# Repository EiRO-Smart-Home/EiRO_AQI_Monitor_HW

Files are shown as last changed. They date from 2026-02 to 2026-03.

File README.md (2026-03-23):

# AQI monitor

This project is a developement board based on a MGM260PD32VNA2 Module from SiliconLabs, SEN5x series sensors and with support for ePaper and other SPI based displays.
This board has been realized for the lack of available options that would satisfy our need in therms of a good air quality sensor. As for most commercial solutions are expensive, or they lack some features, such as Matter connectivity or some types of enviromental sensing. Most of the time they detect only PM2.5 and not PM10 and some do not include VOCs. 
Our targets of sensing values are the followings.
- Temperature
- Humidity
- PM 1.0, PM 2.5, PM 4, PM10
- VOC (index)
- CO2 
- NOx
- Formaldehyde 
- Overall AQI index (calculated)
  
Most of the sensing can be done using SEN55 and two addittional sensors for Formaldehyde and CO2. A SEN69C can also be used, but VCC on the connector is 5V and newer SEN6x are 3.3V powered, so the board has to be modified.

An advantage of using Matter as the default connectivity standard, is the ease of integrating it in any smart home (with also a Thread Border Router). There is no need for vendor specific applications, as all the data will be managed by Matter. This means there is no need for subscription and the device is completely local.

## Hardware Features

 - MGM260 SoM
   * BLE 5.4 Support 
   * Zigbee 3.0 and up
   * OpenThread
   * ARM Cortex M33 @ 80 MHz
   * 3.2MB Flash + 512kB RAM
   * Matrix Vector Processor for ML
 - SHT41 Temp. and Humidity Sensor
 - JTAG-SWD-9 connector
 - SPI expansion 4x2 1.27mm pitch
 - SPI connection for external display 
 - I2C expansion for external SEN5x series sensor node
 - USB-C for power and serial communication

## PICTURES

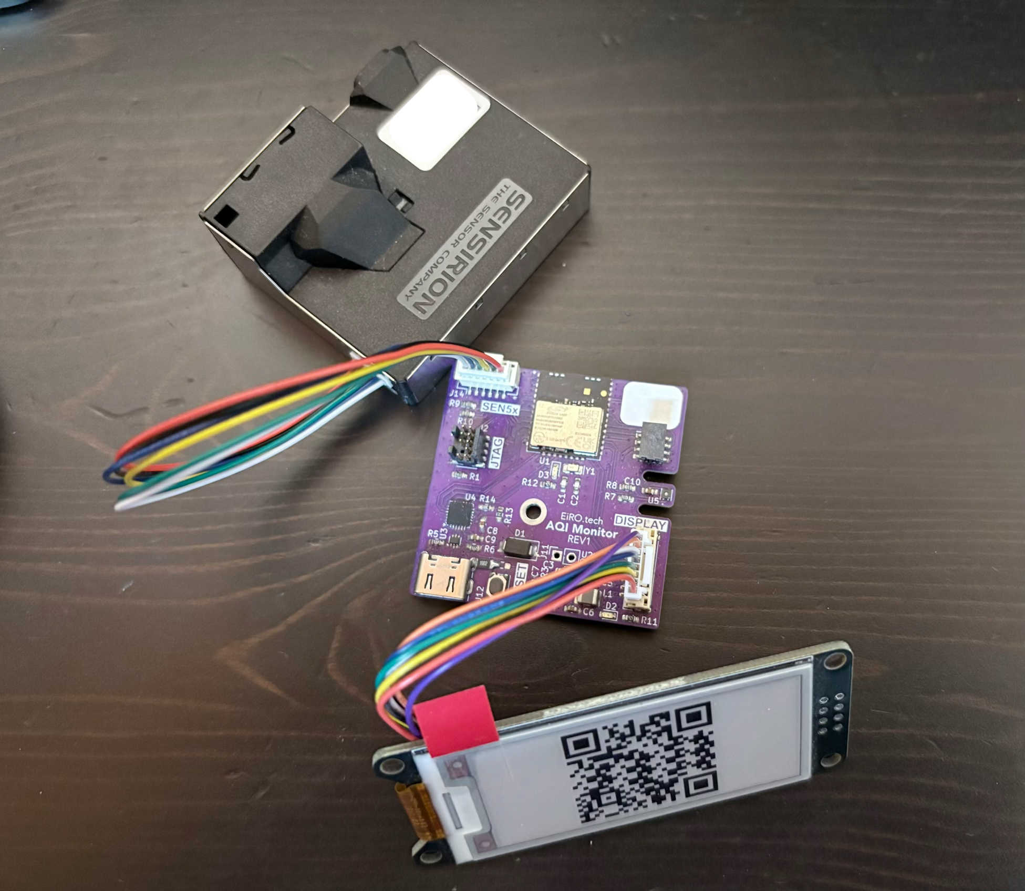
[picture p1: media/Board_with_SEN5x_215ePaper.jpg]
AQI Board with SEN5x


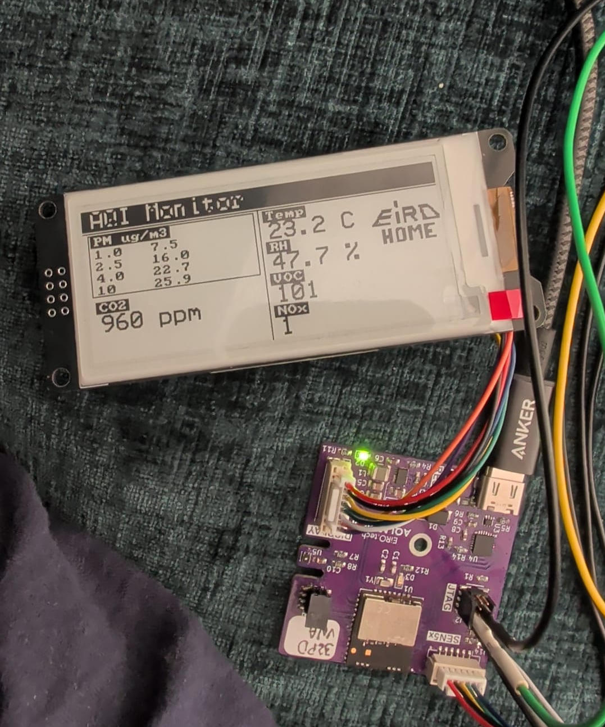
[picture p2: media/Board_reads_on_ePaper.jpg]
AQI Board ePaper_readings


## LICENSE

Copyright Francesco Salmaso - EiRO.tech 2025-2026
This source describes Open Hardware and is licensed under the CERN-
OHL-S v2.
You may redistribute and modify this source and make products using it
under the terms of the CERN-OHL-S v2
(https://ohwr.org/cern ohl s v2.txt ).
This source is distributed WITHOUT ANY EXPRESS OR IMPLIED
WARRANTY, INCLUDING OF MERCHANTABILITY, SATISFACTORY
QUALITY AND FITNESS FOR A PARTICULAR PURPOSE. Please see
the CERN-OHL-S v2 for applicable conditions.
Source location: https://github.com/EiRO-Smart-Home/EiRO_AQI_Monitor_HW
As per CERN-OHL-S v2 section 4, should You produce hardware based
on this source, You must where practicable maintain the Source Location
visible on the external case of the EiRO AQI Monitor or other products you make using
this source.

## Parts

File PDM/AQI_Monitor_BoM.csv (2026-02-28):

Id | Designator | Footprint | Quantity | Designation | Supplier and ref
1 | R14 | R_0603_1608Metric_Pad0.98x0.95mm_HandSolder | 1 | 47k5 |  | v | x
2 | C7 | C_0603_1608Metric_Pad1.08x0.95mm_HandSolder | 1 | 33pF |  | v | x
3 | R6,R5 | R_0603_1608Metric_Pad0.98x0.95mm_HandSolder | 2 | 5k1 |  | v | x
4 | C3 | C_0805_2012Metric_Pad1.18x1.45mm_HandSolder | 1 | 10uF |  | v | x
5 | J14 | JST_GH_BM06B-GHS-TBT_1x06-1MP_P1.25mm_Vertical | 1 | Conn_01x06 |  | ok
6 | R12,R11 | R_0603_1608Metric_Pad0.98x0.95mm_HandSolder | 2 | 470R |  | v | x
7 | C10,C8,C9,C6 | C_0603_1608Metric_Pad1.08x0.95mm_HandSolder | 4 | 100nF |  | v | x
8 | C1,C2 | C_0603_1608Metric_Pad1.08x0.95mm_HandSolder | 2 | 12pF |  | v | x
9 | D1 | D_SMA | 1 | D_Schottky |  | v | x
10 | U4 | QFN-24-1EP_4x4mm_P0.5mm_EP2.6x2.6mm | 1 | CP2102N-Axx-xQFN24 |  | v | x
11 | SW1 | SW_SPST_PTS810 | 1 | SW_Push |  | v | x
12 | R8,R7,R9,R10 | R_0603_1608Metric_Pad0.98x0.95mm_HandSolder | 4 | 100k |  | v | x
13 | C4,C5 | C_0805_2012Metric_Pad1.18x1.45mm_HandSolder | 2 | 22uF |  | v | x
14 | J12 | USB_C_Receptacle_JAE_DX07S016JA1R1500 | 1 | USB_C_Receptacle_USB2.0_16P |  | ok
15 | U1 | MODULE_xGM260P_SIL | 1 | MGM260PB22VNA5 |  | v | xxx
16 | J1 | PinHeader_2x04_P1.27mm_Vertical_SMD | 1 | SPI_EXP |  | v | x
17 | R1 | R_0603_1608Metric_Pad0.98x0.95mm_HandSolder | 1 | 100R |  | v | x
18 | D3,D2 | D_0603_1608Metric_Pad1.05x0.95mm_HandSolder | 2 | LED |  | v | xx
19 | R3 | R_0603_1608Metric_Pad0.98x0.95mm_HandSolder | 1 | 91k |  | v | x
20 | U2 | V-DFN3020-13_DIO | 1 | AP63357DV-7 |  | ok
21 | J11 | PinSocket_1x02_P2.54mm_Vertical | 1 | VIN |  | ok
22 | J13 | JST_GH_BM08B-GHS-TBT_1x08-1MP_P1.25mm_Vertical | 1 | Conn_01x08 |  | v | x
23 | L1 | L_1210_3225Metric_Pad1.42x2.65mm_HandSolder | 1 | 4.7uH |  | v | x
24 | Y1 | Crystal_SMD_MicroCrystal_CC8V-T1A-2Pin_2.0x1.2mm_HandSoldering | 1 | 32.768kHz |  | v | x
25 | J2 | PinHeader_2x05_P1.27mm_Vertical_SMD | 1 | Conn_ARM_JTAG_SWD_10 |  | v | x
26 | R4 | R_0603_1608Metric_Pad0.98x0.95mm_HandSolder | 1 | 30k |  | v | x
27 | R2 | R_0603_1608Metric_Pad0.98x0.95mm_HandSolder | 1 | R |  | ok
28 | U3 | SOT-666 | 1 | USBLC6-2P6 |  | v | x
29 | R13 | R_0603_1608Metric_Pad0.98x0.95mm_HandSolder | 1 | 22k1 |  | v | x
30 | U5 | DFN4_SHT41_SEN | 1 | SHT41-AD1B-R2 |  | ok
31 | J10 | U.FL_Hirose_U.FL-R-SMT-1_Vertical | 1 | Conn_Coaxial |  | v | x
32 | J8,J4,J3,J6,J9,J5,J7 | SolderWirePad_1x01_SMD_1x2mm | 7 | SPARE_GPIO |  | v | x

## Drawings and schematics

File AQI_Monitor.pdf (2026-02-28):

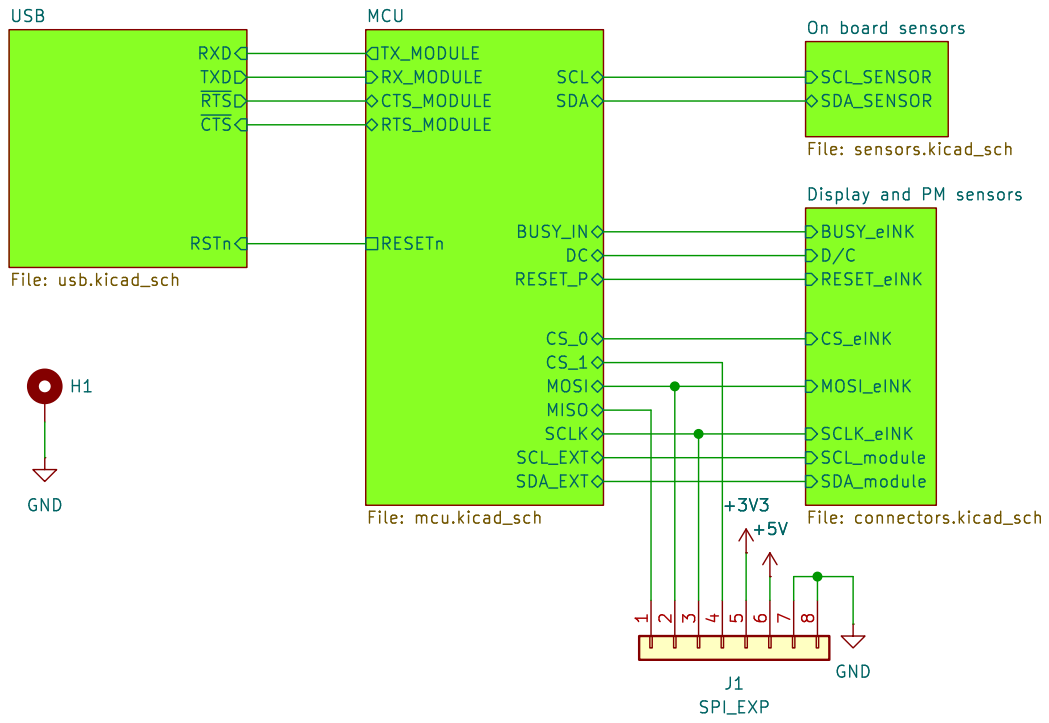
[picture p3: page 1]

~{RTS} USB
SDA_SENSOR On board sensors File: sensors.kicad_sch GND

RESET_P MCU
SCL_module SDA_module Display and PM sensors File: connectors.kicad_sch SCL_SENSOR

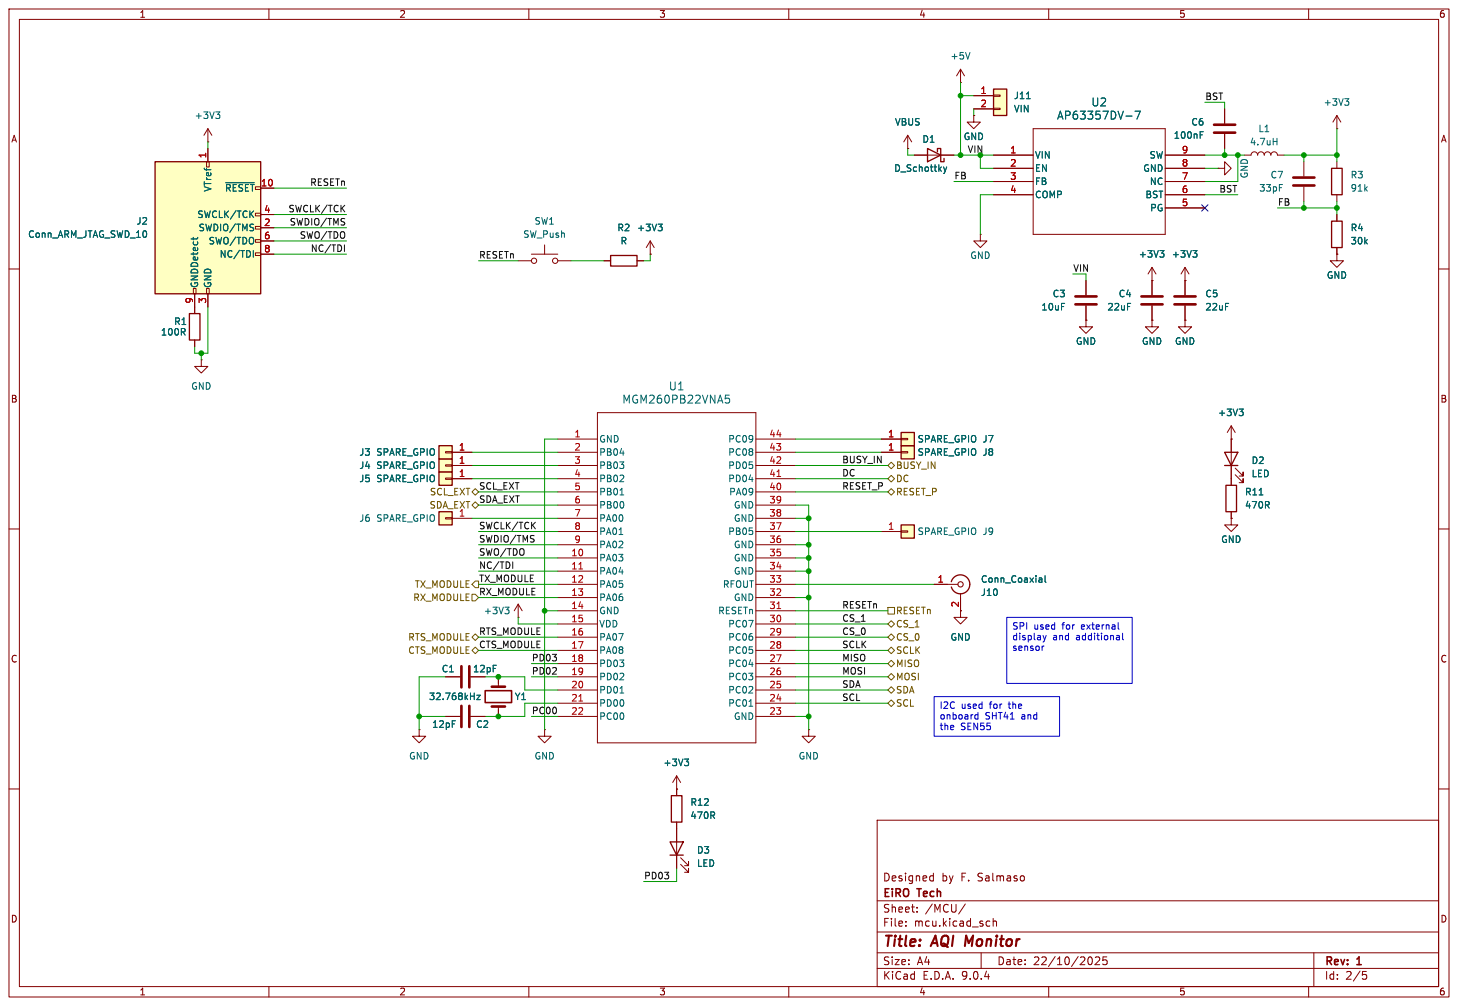
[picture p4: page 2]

3 ~{RESET}10 SWCLK/TCK 4 SWDIO/TMS 2 SWO/TDO 6 NC/TDI 8

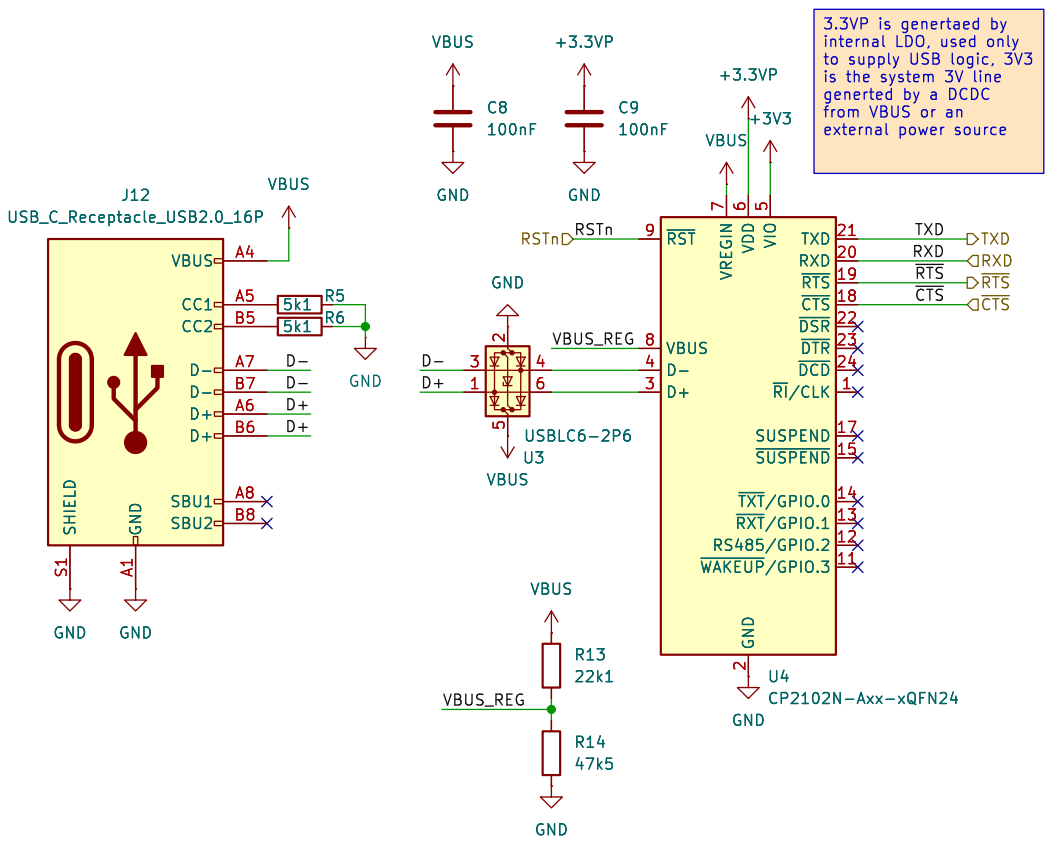
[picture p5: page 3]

to supply USB logic, 3V3
is the system 3V line
generted by a DCDC
from VBUS or an

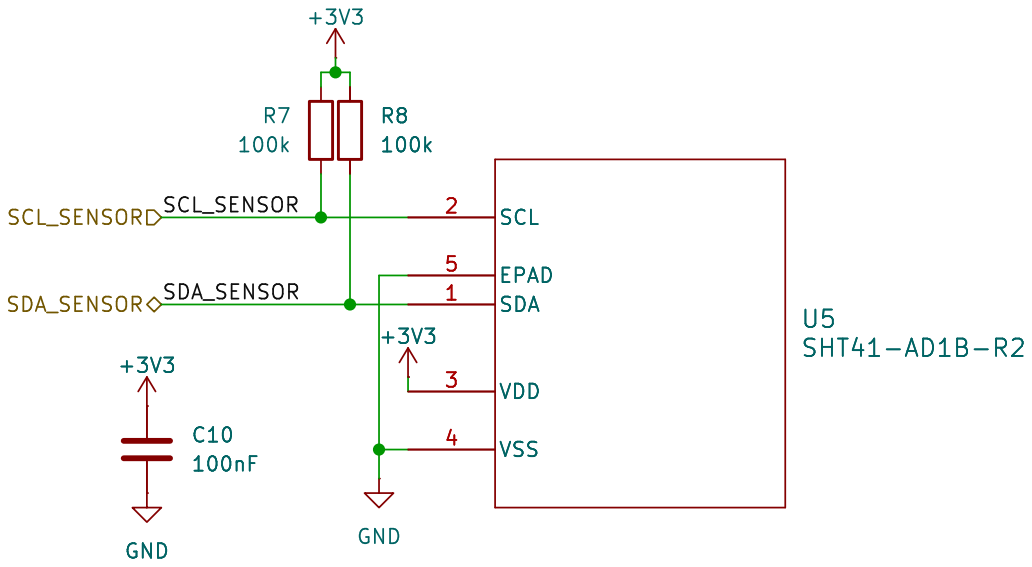
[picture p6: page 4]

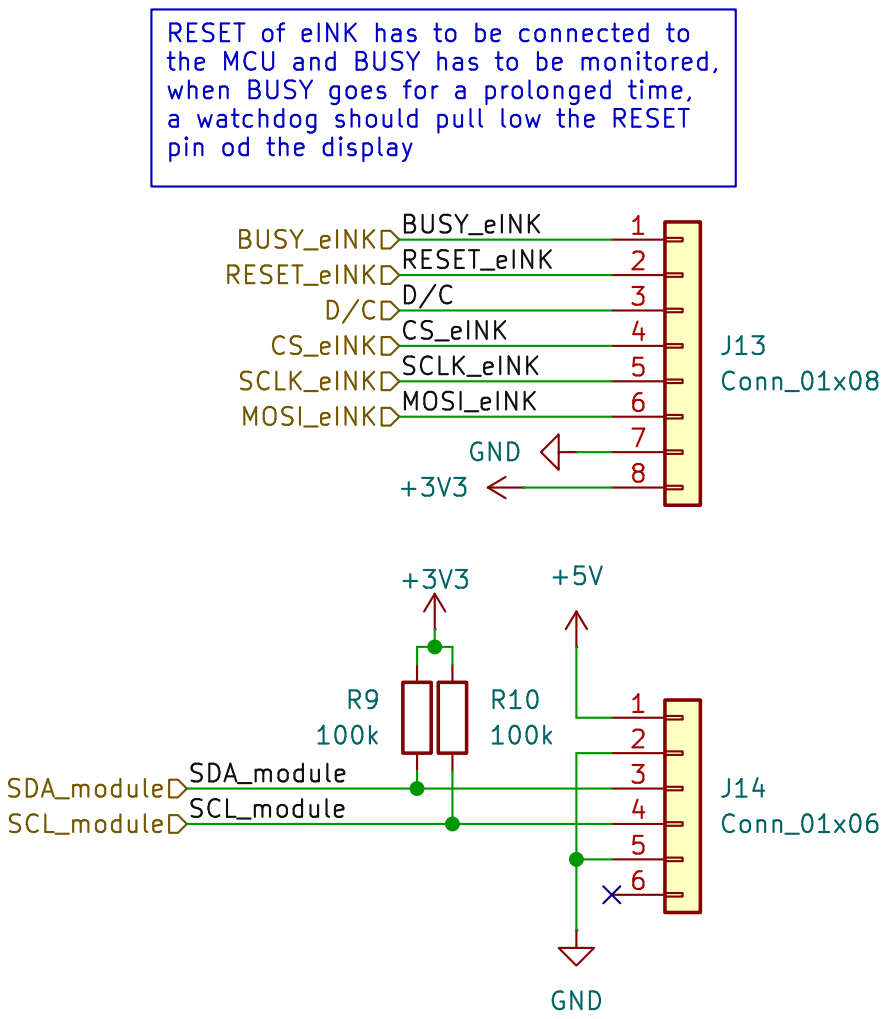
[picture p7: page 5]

pin od the display

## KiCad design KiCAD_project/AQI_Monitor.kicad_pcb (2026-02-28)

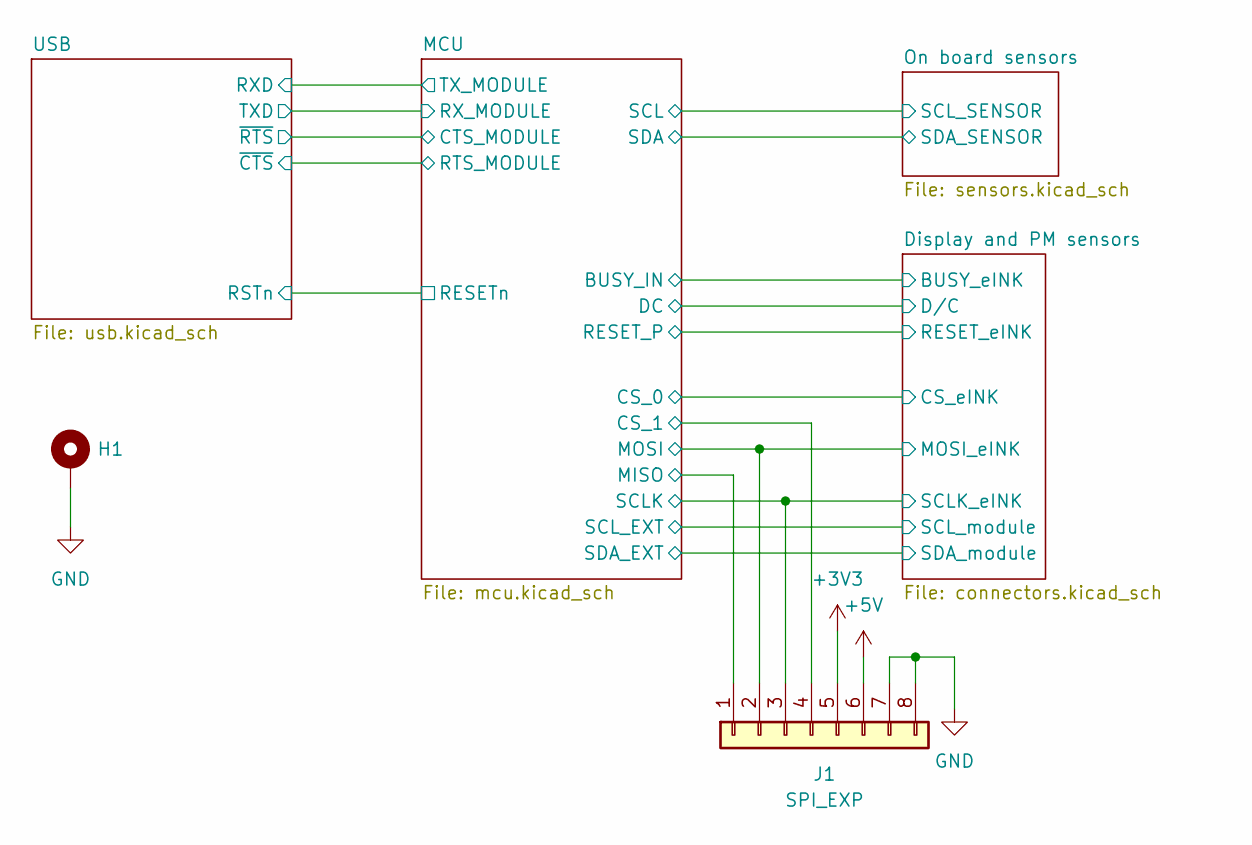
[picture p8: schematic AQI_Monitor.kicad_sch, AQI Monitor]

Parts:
H1: MountingHole_Pad; MountingHole_2.7mm_M2.5_DIN965_Pad
J1: SPI_EXP; PinHeader_2x04_P1.27mm_Vertical_SMD

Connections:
+3V3: J1.5; also elsewhere on the board
+5V: J1.6; also elsewhere on the board
/Display and PM sensors/MOSI_eINK: J1.2; also elsewhere on the board
/Display and PM sensors/SCLK_eINK: J1.3; also elsewhere on the board
/MCU/CS_1: J1.4; also elsewhere on the board
/MCU/MISO: J1.1; also elsewhere on the board
GND: H1.1, J1.7, J1.8; also elsewhere on the board

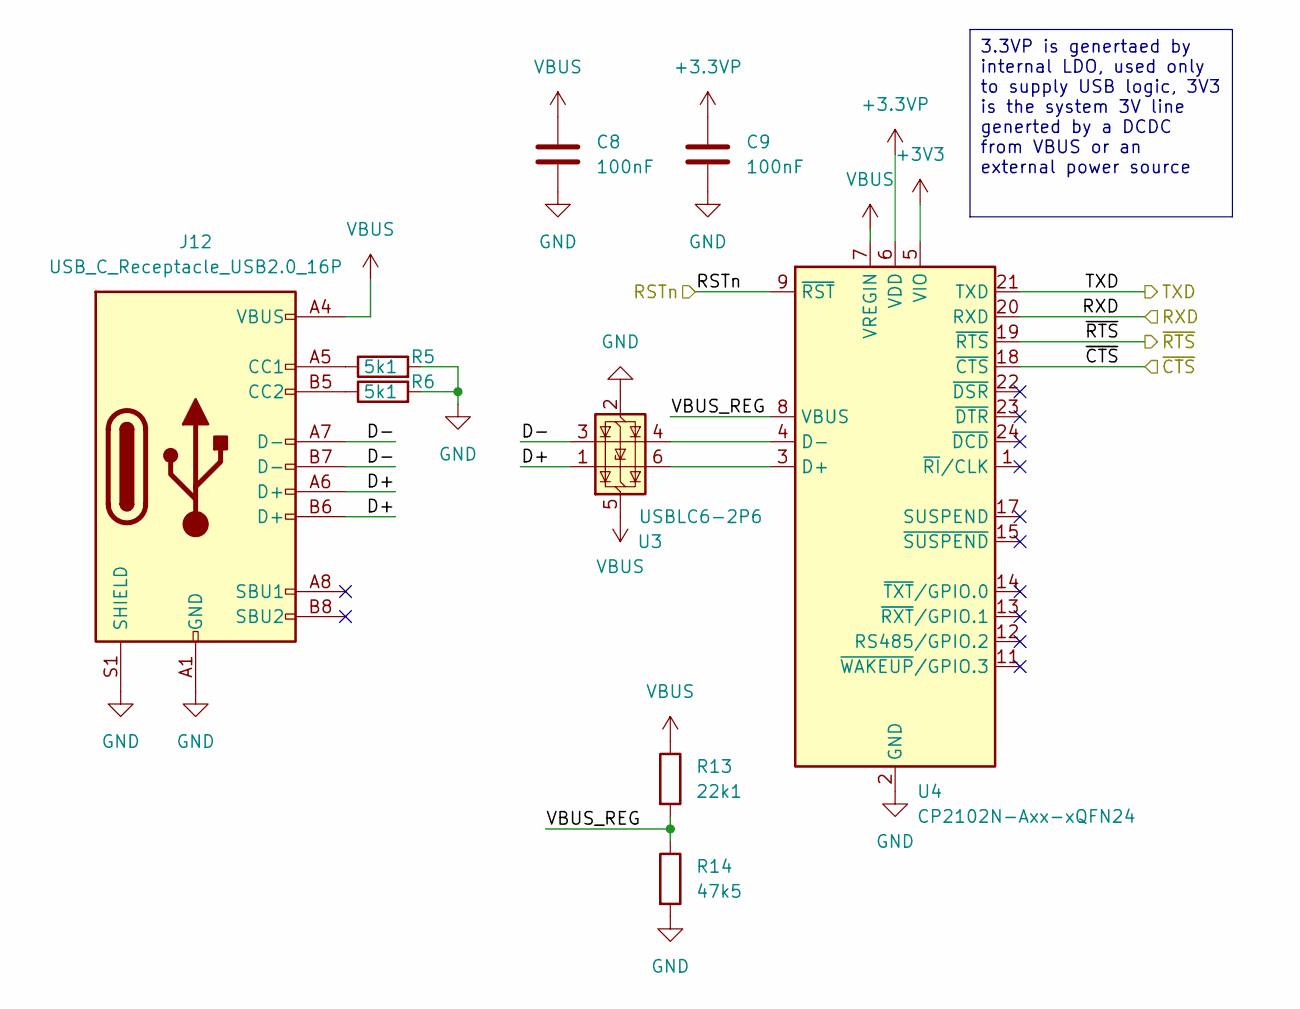
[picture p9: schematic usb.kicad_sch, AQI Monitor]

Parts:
C8, C9: 100nF; C_0603_1608Metric_Pad1.08x0.95mm_HandSolder
J12: USB_C_Receptacle_USB2.0_16P; USB_C_Receptacle_JAE_DX07S016JA1R1500
R5, R6: 5k1; R_0603_1608Metric_Pad0.98x0.95mm_HandSolder
R13: 22k1; R_0603_1608Metric_Pad0.98x0.95mm_HandSolder
R14: 47k5; R_0603_1608Metric_Pad0.98x0.95mm_HandSolder
U3: USBLC6-2P6; SOT-666
U4: CP2102N-Axx-xQFN24; QFN-24-1EP_4x4mm_P0.5mm_EP2.6x2.6mm

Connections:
+3.3VP: C9.1, U4.6 (VDD)
+3V3: U4.5 (VIO); also elsewhere on the board
/MCU/CTS_MODULE: U4.19 (~RTS); also elsewhere on the board
/MCU/RESETn: U4.9 (~RST); also elsewhere on the board
/MCU/RTS_MODULE: U4.18 (~CTS); also elsewhere on the board
/MCU/RX_MODULE: U4.21 (TXD); also elsewhere on the board
/MCU/TX_MODULE: U4.20 (RXD); also elsewhere on the board
/USB/D+: J12.A6 (D+), J12.B6 (D+), U3.1 (I/O1)
/USB/D-: J12.A7 (D-), J12.B7 (D-), U3.3 (I/O2)
/USB/VBUS_REG: R13.2, R14.1, U4.8 (VBUS)
GND: C8.2, C9.2, J12.A1 (GND), J12.A12 (GND), J12.B1 (GND), J12.B12 (GND), J12.S1 (SHIELD), R5.2, R6.2, R14.2, U3.2 (GND), U4.2 (GND), U4.25 (GND); also elsewhere on the board
unnamed: J12.A5 (CC1), R5.1
unnamed: J12.B5 (CC2), R6.1
unnamed: U3.6 (I/O1), U4.3 (D+)
unnamed: U3.4 (I/O2), U4.4 (D-)
VBUS: C8.1, J12.A4 (VBUS), J12.A9 (VBUS), J12.B4 (VBUS), J12.B9 (VBUS), R13.1, U3.5 (VBUS), U4.7 (VREGIN); also elsewhere on the board

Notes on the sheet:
3.3VP is genertaed by internal LDO, used only to supply USB logic, 3V3 is the system 3V line generted by a DCDC from VBUS or an external power source

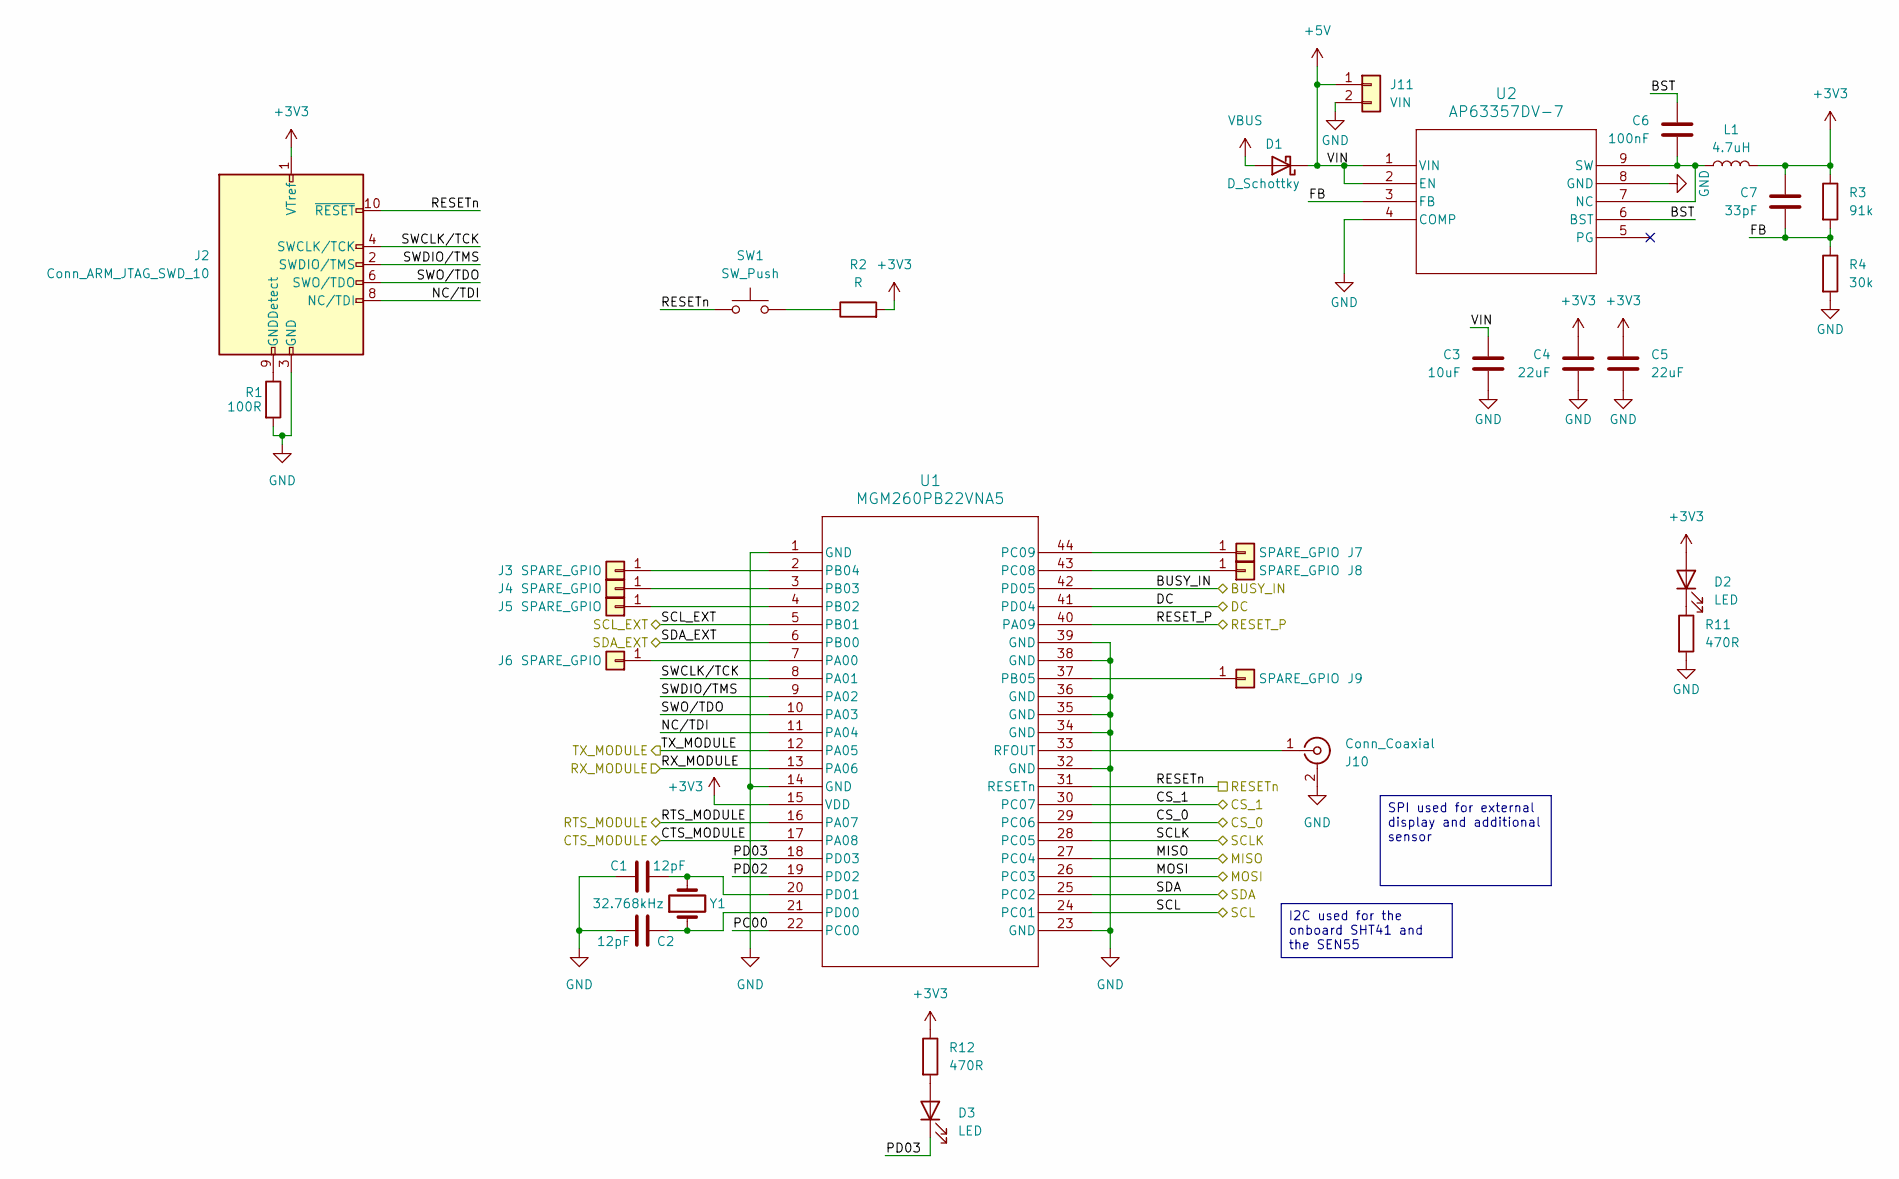
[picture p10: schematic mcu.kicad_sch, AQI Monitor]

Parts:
C1, C2: 12pF; C_0603_1608Metric_Pad1.08x0.95mm_HandSolder
C3: 10uF; C_0805_2012Metric_Pad1.18x1.45mm_HandSolder
C4, C5: 22uF; C_0805_2012Metric_Pad1.18x1.45mm_HandSolder
C6: 100nF; C_0603_1608Metric_Pad1.08x0.95mm_HandSolder
C7: 33pF; C_0603_1608Metric_Pad1.08x0.95mm_HandSolder
D1: D_Schottky; D_SMA
D2, D3: LED; D_0603_1608Metric_Pad1.05x0.95mm_HandSolder
J2: Conn_ARM_JTAG_SWD_10; PinHeader_2x05_P1.27mm_Vertical_SMD
J3, J4, J5, J6, J7, J8, J9: SPARE_GPIO; SolderWirePad_1x01_SMD_1x2mm
J10: Conn_Coaxial; U.FL_Hirose_U.FL-R-SMT-1_Vertical
J11: VIN; PinSocket_1x02_P2.54mm_Vertical
L1: 4.7uH; L_1210_3225Metric_Pad1.42x2.65mm_HandSolder
R1: 100R; R_0603_1608Metric_Pad0.98x0.95mm_HandSolder
R2: R; R_0603_1608Metric_Pad0.98x0.95mm_HandSolder
R3: 91k; R_0603_1608Metric_Pad0.98x0.95mm_HandSolder
R4: 30k; R_0603_1608Metric_Pad0.98x0.95mm_HandSolder
R11, R12: 470R; R_0603_1608Metric_Pad0.98x0.95mm_HandSolder
SW1: SW_Push; SW_SPST_PTS810
U1: MGM260PB22VNA5; MODULE_xGM260P_SIL
U2: AP63357DV-7; V-DFN3020-13_DIO
Y1: 32.768kHz; Crystal_SMD_MicroCrystal_CC8V-T1A-2Pin_2.0x1.2mm_HandSolder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

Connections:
+3V3: C4.1, C5.1, C7.1, D2.2 (A), J2.1 (VTref), L1.2, R2.2, R3.1, R12.1, U1.15 (VDD); also elsewhere on the board
+5V: C3.1, D1.1 (K), J11.1, U2.1 (VIN), U2.2 (EN); also elsewhere on the board
/Display and PM sensors/BUSY_eINK: U1.42 (PD05); also elsewhere on the board
/Display and PM sensors/CS_eINK: U1.29 (PC06); also elsewhere on the board
/Display and PM sensors/D/C: U1.41 (PD04); also elsewhere on the board
/Display and PM sensors/MOSI_eINK: U1.26 (PC03); also elsewhere on the board
/Display and PM sensors/RESET_eINK: U1.40 (PA09); also elsewhere on the board
/Display and PM sensors/SCLK_eINK: U1.28 (PC05); also elsewhere on the board
/Display and PM sensors/SCL_module: U1.5 (PB01); also elsewhere on the board
/Display and PM sensors/SDA_module: U1.6 (PB00); also elsewhere on the board
/MCU/BST: C6.1, U2.6 (BST)
/MCU/CS_1: U1.30 (PC07); also elsewhere on the board
/MCU/CTS_MODULE: U1.17 (PA08); also elsewhere on the board
/MCU/FB: C7.2, R3.2, R4.1, U2.3 (FB)
/MCU/MISO: U1.27 (PC04); also elsewhere on the board
/MCU/PC00: U1.22 (PC00)
/MCU/PD02: U1.19 (PD02)
/MCU/PD03: D3.1 (K), U1.18 (PD03)
/MCU/RESETn: J2.10 (~RESET), SW1.1, U1.31 (RESETn); also elsewhere on the board
/MCU/RTS_MODULE: U1.16 (PA07); also elsewhere on the board
/MCU/RX_MODULE: U1.13 (PA06); also elsewhere on the board
/MCU/SCL: U1.24 (PC01); also elsewhere on the board
/MCU/SDA: U1.25 (PC02); also elsewhere on the board
/MCU/TX_MODULE: U1.12 (PA05); also elsewhere on the board
GND: C1.1, C2.2, C3.2, C4.2, C5.2, J2.3 (GND), J2.5 (GND), J10.2 (Ext), J11.2, R1.2, R4.2, R11.2, U1.1 (GND), U1.14 (GND), U1.23 (GND), U1.32 (GND), U1.34 (GND), U1.35 (GND), U1.36 (GND), U1.38 (GND), U1.39 (GND), U2.4 (COMP), U2.8 (GND); also elsewhere on the board
unnamed: D2.1 (K), R11.1
unnamed: D3.2 (A), R12.2
unnamed: J2.9 (GNDDetect), R1.1
unnamed: J3.1, U1.2 (PB04)
unnamed: J4.1, U1.3 (PB03)
unnamed: J5.1, U1.4 (PB02)
unnamed: J6.1, U1.7 (PA00)
unnamed: J7.1, U1.44 (PC09)
unnamed: J8.1, U1.43 (PC08)
unnamed: J9.1, U1.37 (PB05)
unnamed: J10.1 (In), U1.33 (RFOUT)
unnamed: R2.1, SW1.2
unnamed: C2.1, U1.21 (PD00), Y1.1
unnamed: C1.2, U1.20 (PD01), Y1.2
unnamed: C6.2, L1.1, U2.7 (NC), U2.9 (SW)
VBUS: D1.2 (A); also elsewhere on the board

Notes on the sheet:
I2C used for the onboard SHT41 and the SEN55
SPI used for external display and additional sensor

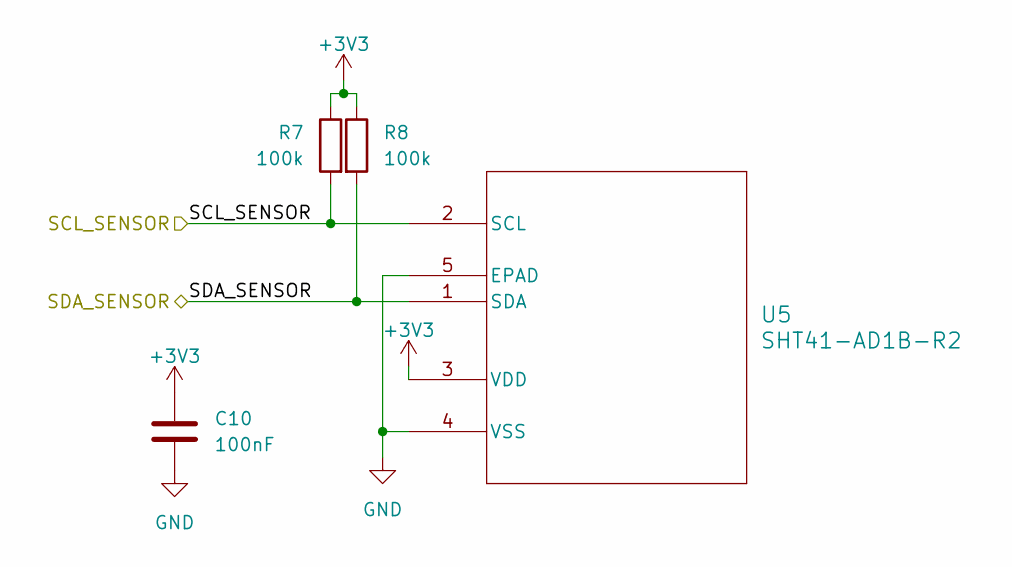
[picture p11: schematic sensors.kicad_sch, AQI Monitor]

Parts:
C10: 100nF; C_0603_1608Metric_Pad1.08x0.95mm_HandSolder
R7, R8: 100k; R_0603_1608Metric_Pad0.98x0.95mm_HandSolder
U5: SHT41-AD1B-R2; DFN4_SHT41_SEN

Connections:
+3V3: C10.1, R7.1, R8.1, U5.3 (VDD); also elsewhere on the board
/MCU/SCL: R7.2, U5.2 (SCL); also elsewhere on the board
/MCU/SDA: R8.2, U5.1 (SDA); also elsewhere on the board
GND: C10.2, U5.4 (VSS), U5.5 (EPAD); also elsewhere on the board

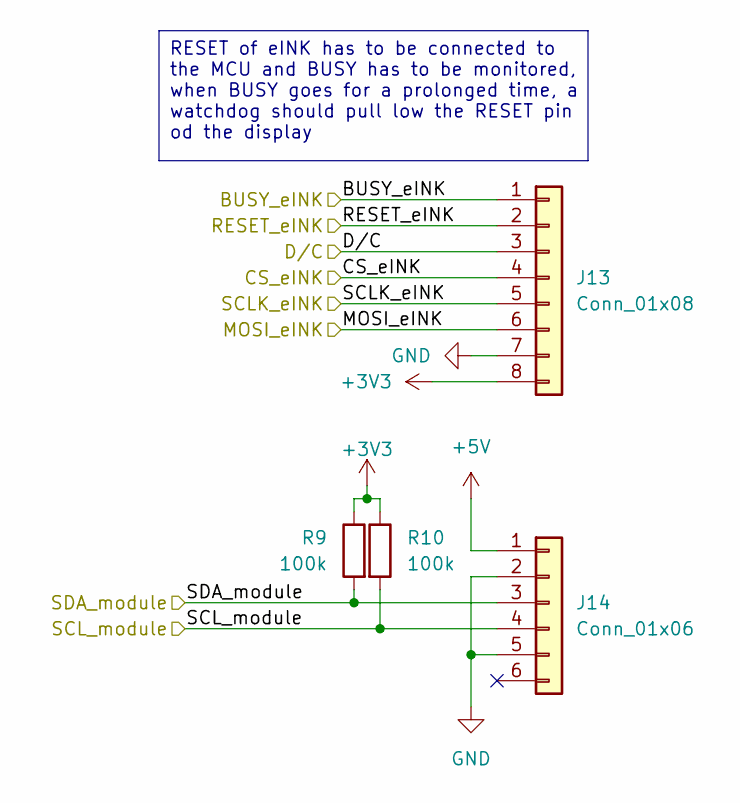
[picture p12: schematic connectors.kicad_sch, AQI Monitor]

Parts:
J13: Conn_01x08; JST_GH_BM08B-GHS-TBT_1x08-1MP_P1.25mm_Vertical
J14: Conn_01x06; JST_GH_BM06B-GHS-TBT_1x06-1MP_P1.25mm_Vertical
R9, R10: 100k; R_0603_1608Metric_Pad0.98x0.95mm_HandSolder

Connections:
+3V3: J13.8, R9.1, R10.1; also elsewhere on the board
+5V: J14.1; also elsewhere on the board
/Display and PM sensors/BUSY_eINK: J13.1; also elsewhere on the board
/Display and PM sensors/CS_eINK: J13.4; also elsewhere on the board
/Display and PM sensors/D/C: J13.3; also elsewhere on the board
/Display and PM sensors/MOSI_eINK: J13.6; also elsewhere on the board
/Display and PM sensors/RESET_eINK: J13.2; also elsewhere on the board
/Display and PM sensors/SCLK_eINK: J13.5; also elsewhere on the board
/Display and PM sensors/SCL_module: J14.4, R10.2; also elsewhere on the board
/Display and PM sensors/SDA_module: J14.3, R9.2; also elsewhere on the board
GND: J13.7, J14.2, J14.5; also elsewhere on the board

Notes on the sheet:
RESET of eINK has to be connected to the MCU and BUSY has to be monitored, when BUSY goes for a prolonged time, a watchdog should pull low the RESET pin od the display

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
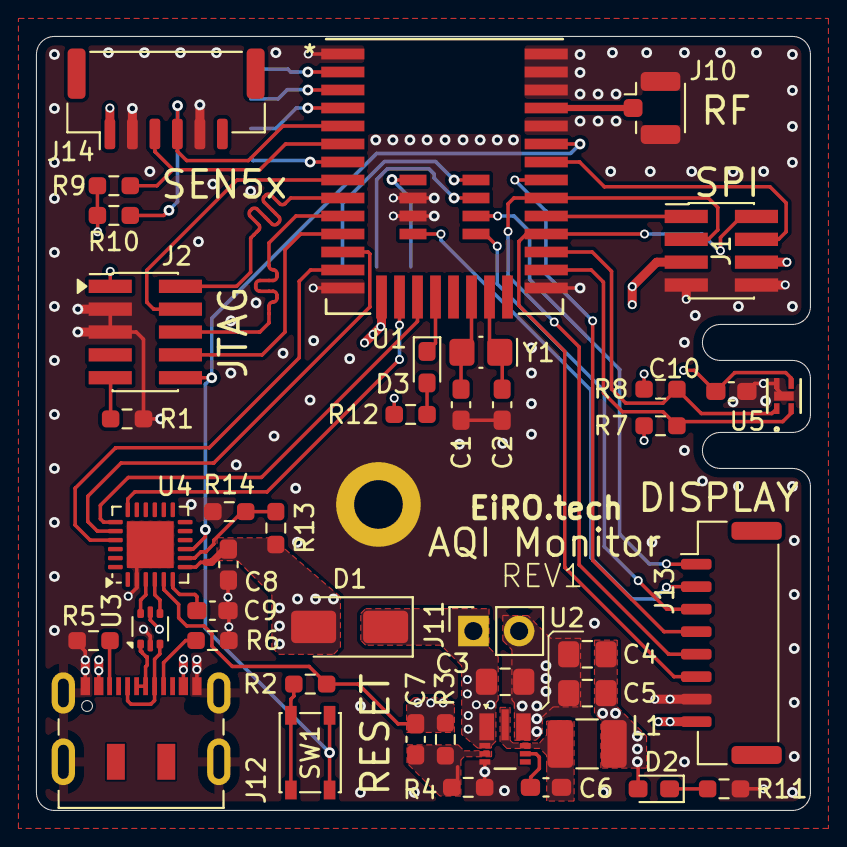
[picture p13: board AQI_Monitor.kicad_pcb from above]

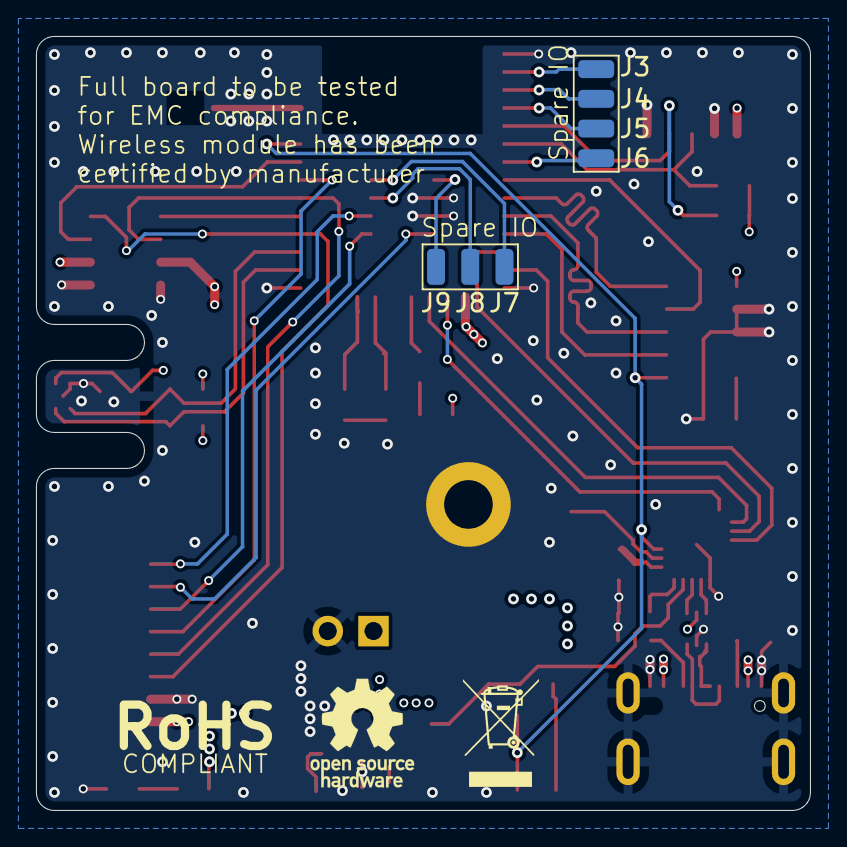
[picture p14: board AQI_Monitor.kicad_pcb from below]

Board: 4 copper layers, 43.0 x 43.0 mm, 50 parts (7 on the bottom side), 51 nets.

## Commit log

2026-02-28 First commit
    Initial KiCAD files, gerber and schematic of the AQI monitor (already produced)
    [AQI_Monitor.kicad_pcb, AQI_Monitor.kicad_sch, AQI_Monitor_BoM.csv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]
2026-03-23 Updated files, added license
    Updated the Readme, inserted a new image, fixed the preexisting images (converted from .heic to .jpg). Added license.
